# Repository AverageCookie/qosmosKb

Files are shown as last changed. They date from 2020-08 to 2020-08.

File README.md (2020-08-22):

# TKL keyboard "from scratch"

Being bored during the covid lockdown, I tried to learn a bit about electronics how my mechanical keyboard works. To practice, I wanted to build my own PCB, and why not try to build a usable keyboard.

## Disclamer : language mastery

I'm from France, I learn english mainly thanks to pop culture (TV shows/movies/videogames and lurking on reddit), so let me know if some sentences are gibberish or if I'm not clear enough.

## Table of Contents

* [Learning sources](#learning-sources)
* [Software/equipment/services used](#software-equipment-services-used)
* [Schematics](#schematics)
* [PCB](#pcb-design)
* [Soldering](#soldering)
* [Flashing Firmware](#flashing-firmware)
* [Troubles oh troubles](#troubles-oh-troubles)

## Learning sources

I learned how matrices works thanks to [r/MechanicalKeyboards/](https://www.reddit.com/r/MechanicalKeyboards/), and soon found [ruiqimao's awesome guide](https://github.com/ruiqimao/keyboard-pcb-guide). As you will see, the schematics I made are very similar to his.

## Software/equipment/services used

* For schematics and pcb design, I used [Kicad](https://kicad-pcb.org/).
* For pcb manufacturing, I went to [JLCPCB](https://jlcpcb.com/).
* For components, I went to [Digikey](https://www.digikey.com/) and [RS components](https://www.rs-online.com/)
* For soldering tools and materials, I bought from divers Amazon sellers :
    * [Soldering tools](https://www.amazon.fr/gp/product/B07PLTB46N/ref=ppx_yo_dt_b_asin_title_o06_s01?ie=UTF8&psc=1)
    * [Flux](https://www.amazon.fr/gp/product/B002OB4CIE/ref=ppx_yo_dt_b_asin_title_o05_s00)
    * [Solder](https://www.amazon.fr/gp/product/B07PDFF5NZ/ref=ppx_yo_dt_b_asin_title_o06_s01)
* For plate and case design, I used [Blender](https://www.blender.org/),
* For plate and case printing, I used my [Ender3](https://www.ender3.fr/) 3D printer.
* for switches and stabilizers, I bought from [kbdfans](https://kbdfans.com/)

## Schematics

Inspired by [u/Ryvaeus](https://www.reddit.com/r/MechanicalKeyboards/comments/4qdu9o/help_ive_planned_my_matrix_and_teensy_pinout_for/), I went for a 12*9 matrice :

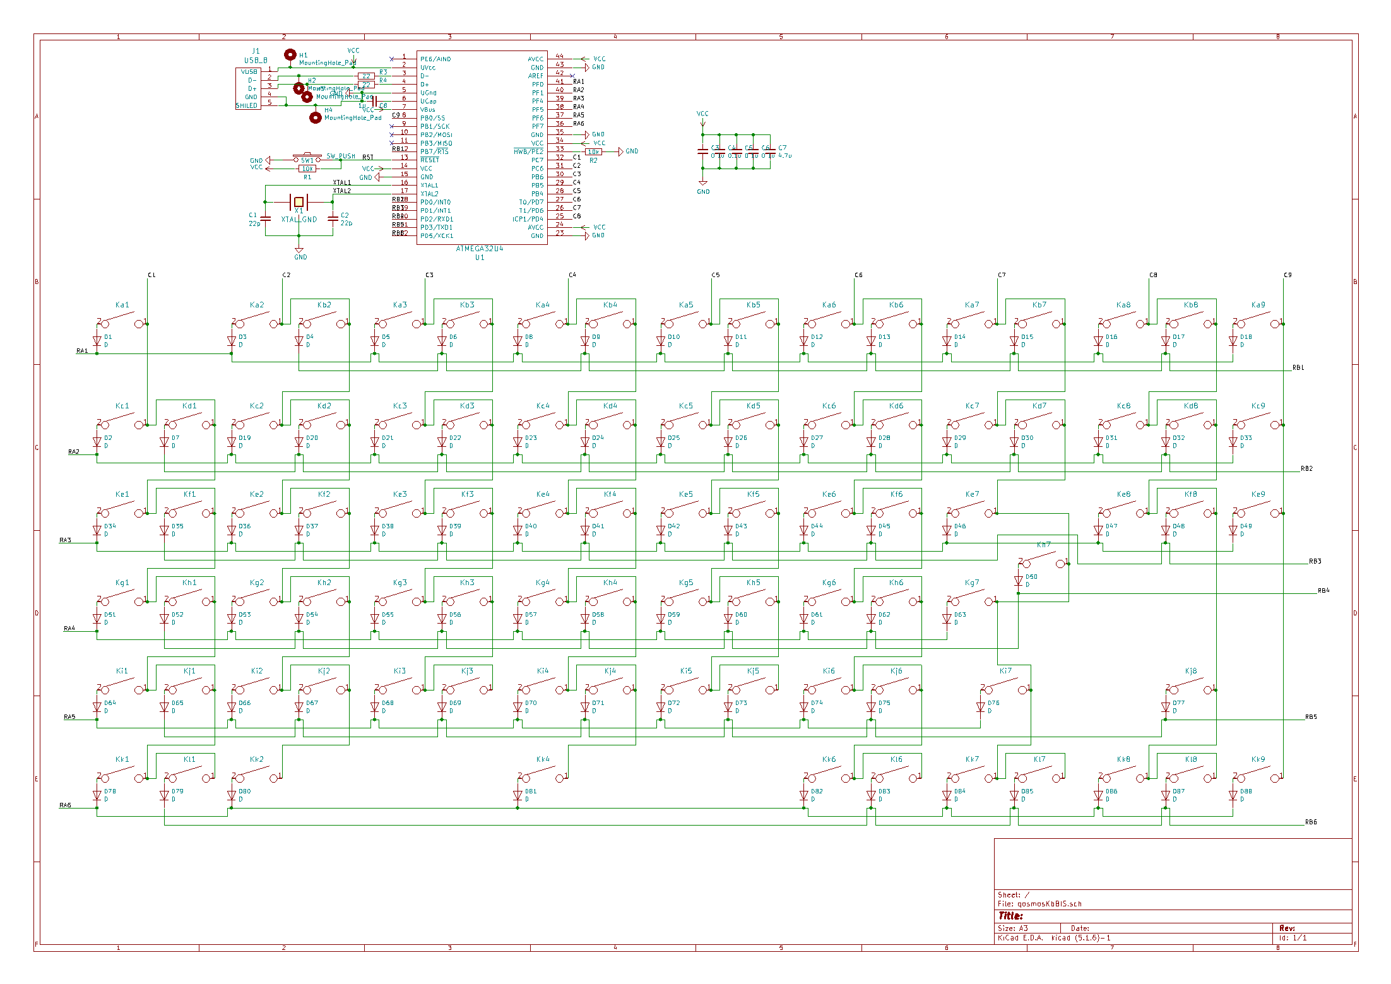
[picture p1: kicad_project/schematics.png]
Schematic


I did a first try with micro USB, but had a lot of problems soldering correctly, so I made a USB B + holes (so i can have an option to solder a non removable cable) 2nd version.

## PCB Design

It was the first PCB I designed, I'm pretty proud but I guess there might be a problem as you will see right bellow. 
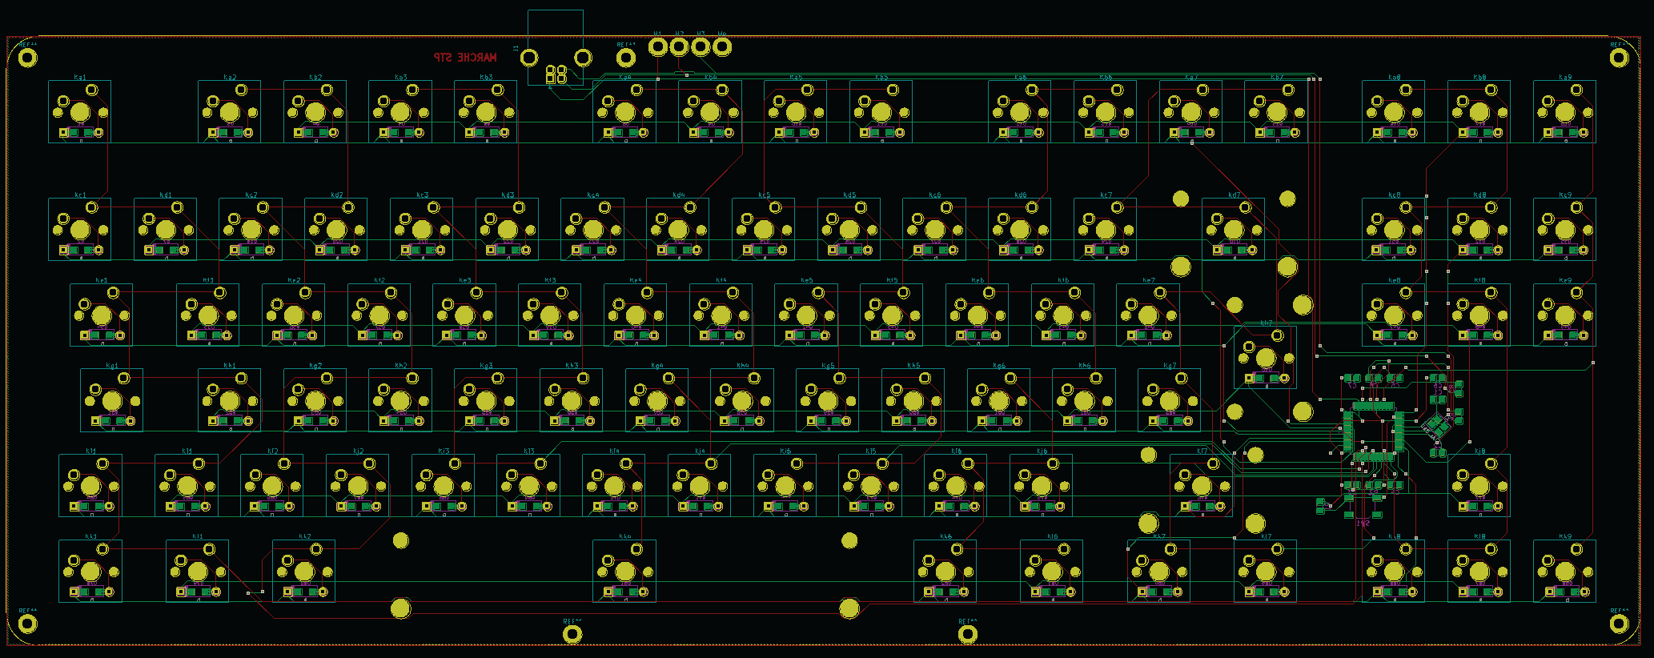
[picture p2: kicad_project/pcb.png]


## Soldering

I have not soldered diodes for now because of the issues you will learn about in the next chapter.

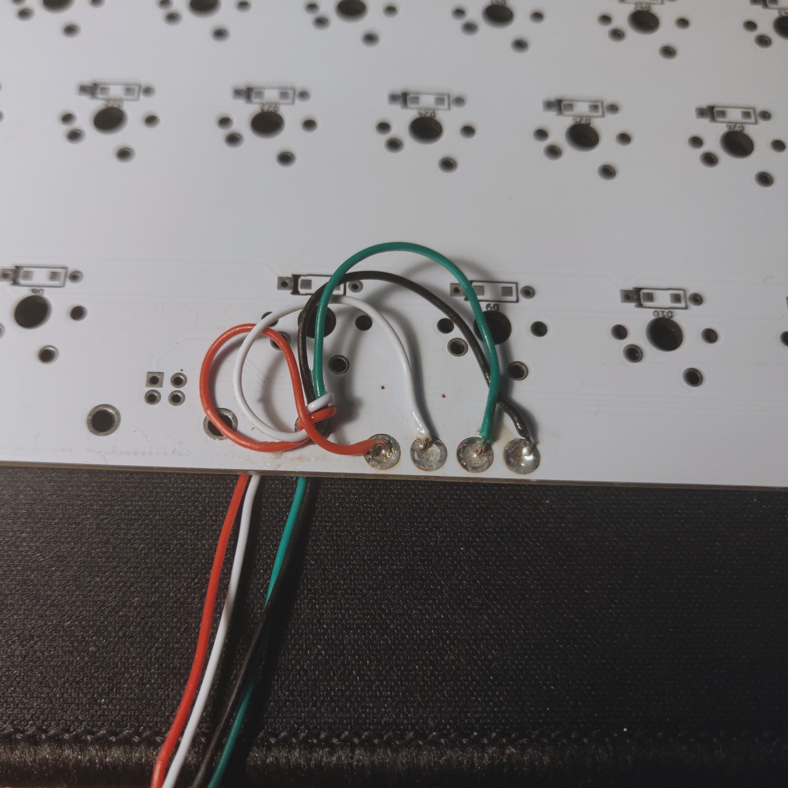
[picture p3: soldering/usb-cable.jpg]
USB cable soldering

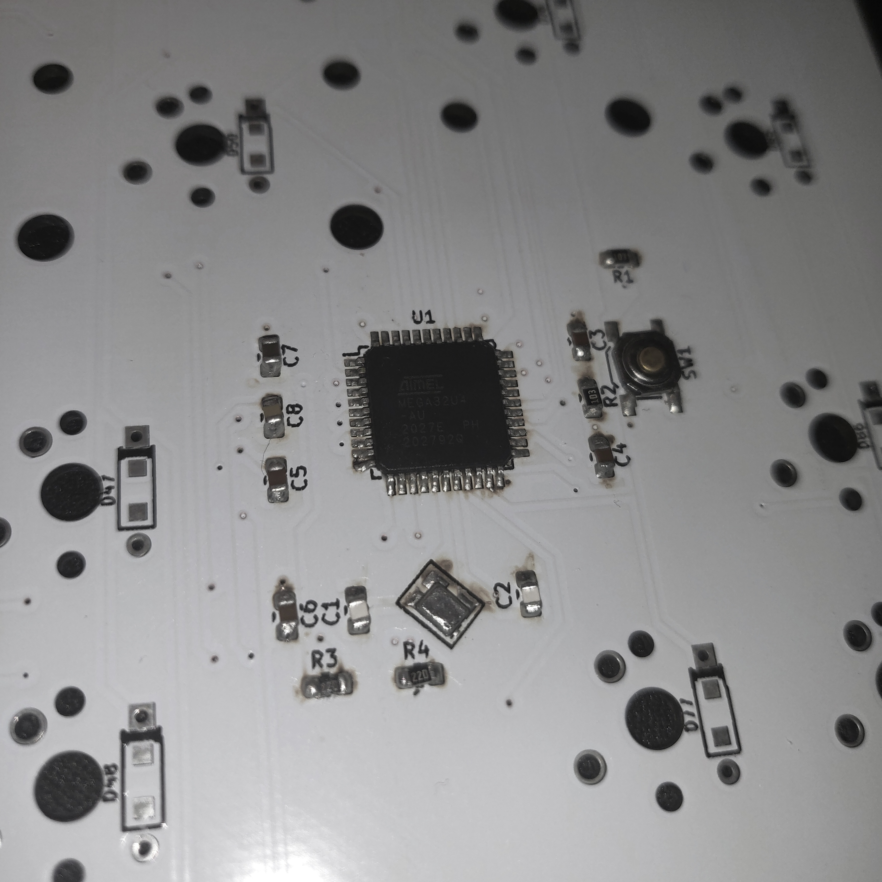
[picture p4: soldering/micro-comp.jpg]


## Flashing Firmware

I plugged it into my desktop, pressed the RESET button, and flashed it with QMK Toolbox (there was no error). But then nothing, so I unplugged and replugged it, to have windows tel me "USB descriptor failed".

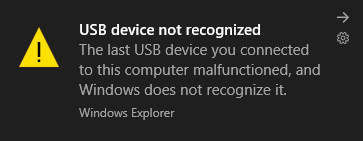
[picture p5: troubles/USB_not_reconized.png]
Screenshot Error 1

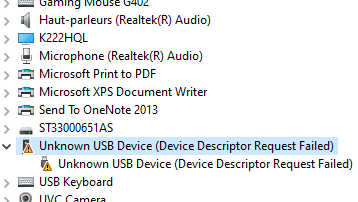
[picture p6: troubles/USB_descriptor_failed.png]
Screenshot Error 2


## Troubles oh troubles

I tried to re-install my USB controllers driver, I tried to flash a few more time, even changing from QMK toolbox to QMK flasher, but I could not make it work.

Then I tried to plug it on my laptop (XPS13, with USB C adaptator), and it was recognised as the keyboard it is destined to be !

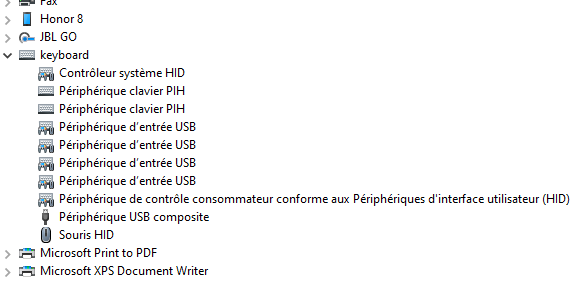
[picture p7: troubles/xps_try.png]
XPS success


Thinking the USB Male port could be the problem, I replaced the cable by one I know works perfectly. It was unproductive, and strangely it does not work anymore on my laptop (same errors as in my desktop) I tried again to re-install my USB controllers driver on both machines, nothing.

I tried to discharge capacitors before plugging it in, and it seems to connect and disconnect maybe 5 times before showing me the "USB descriptor failed" error.

I just tried to get into DFU mode by using the RESET button, and it does not even work..

You can find all the sources (except the v1 schematics, I cannot find it, I think I threw it) in the repo.

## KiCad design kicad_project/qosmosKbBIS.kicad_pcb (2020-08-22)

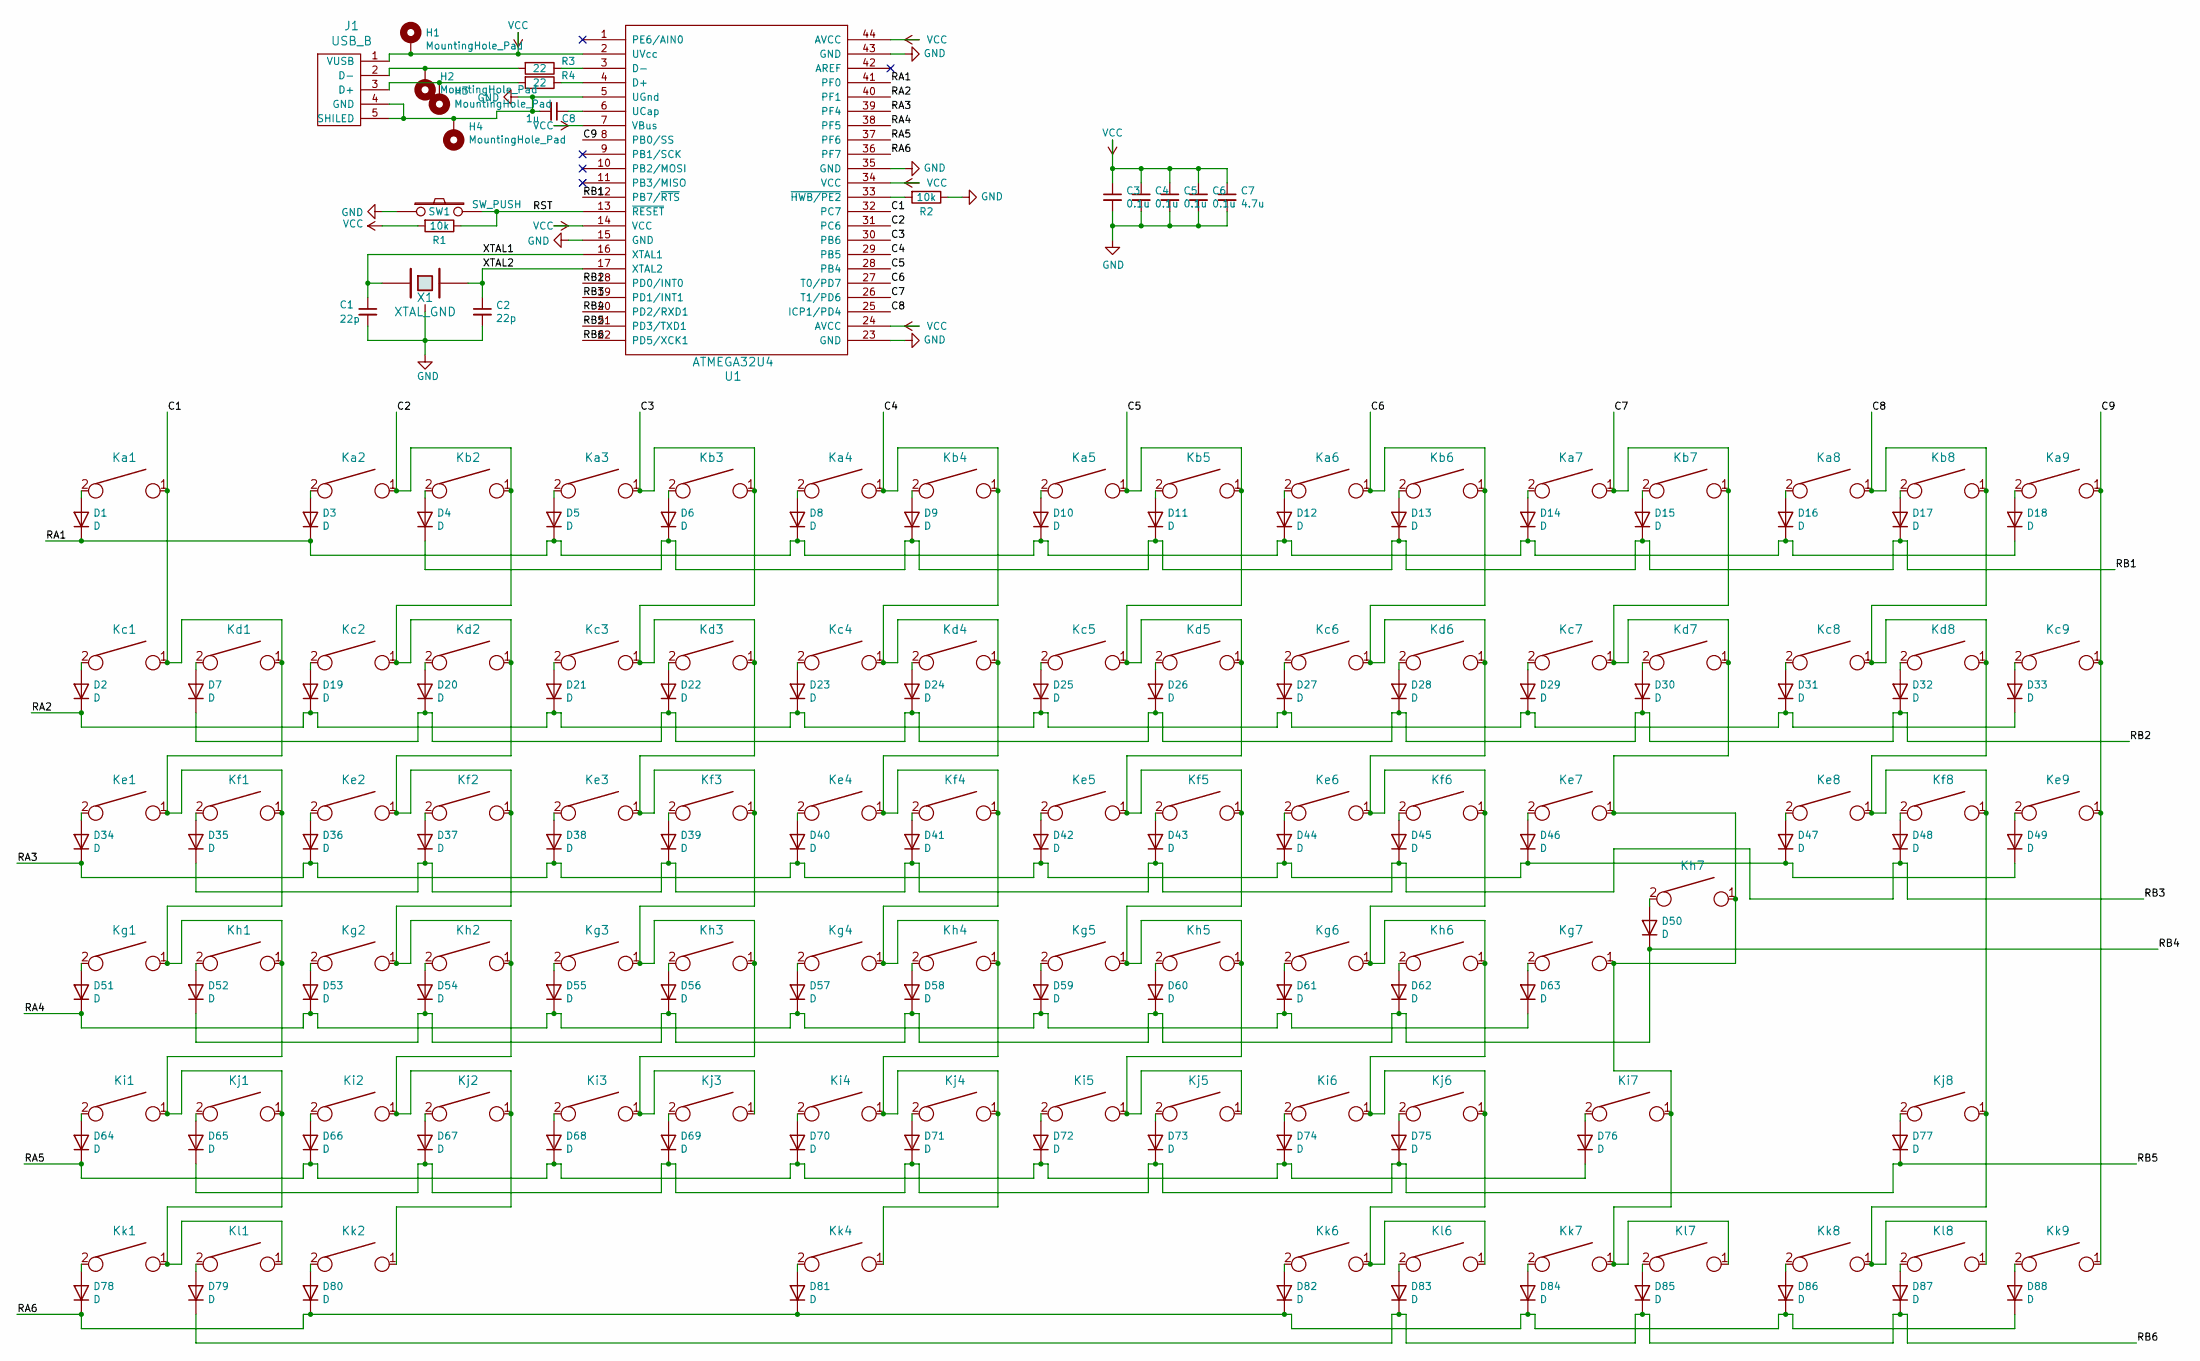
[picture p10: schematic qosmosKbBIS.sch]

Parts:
C1, C2: 22p; C_0805_2012Metric_Pad1.15x1.40mm_HandSolder
C3, C4, C5, C6: 0.1u; C_0805_2012Metric_Pad1.15x1.40mm_HandSolder
C7: 4.7u; C_0805_2012Metric_Pad1.15x1.40mm_HandSolder
C8: 1u; C_0805_2012Metric_Pad1.15x1.40mm_HandSolder
D1, D2, D3, D4, D5, D6, D7, D8, D9, D10, D11, D12, D13, D14, D15, D16, D17, D18, D19, D20, D21, D22, D23, D24, D25, D26, D27, D28, D29, D30, D31, D32, D33, D34, D35, D36, D37, D38, D39, D40, D41, D42, D43, D44, D45, D46, D47, D48, D49, D50, D51, D52, D53, D54, D55, D56, D57, D58, D59, D60, D61, D62, D63, D64, D65, D66, D67, D68, D69, D70, D71, D72, D73, D74, D75, D76, D77, D78, D79, D80, D81, D82, D83, D84, D85, D86, D87, D88: D; D_SOD123_axial
H1, H2, H3, H4: MountingHole_Pad; MountingHole_2.2mm_M2_ISO14580_Pad
J1: USB_B; USB_B_OST_USB-B1HSxx_Horizontal
Ka1, Ka2, Ka3, Ka4, Ka5, Ka6, Ka7, Ka8, Ka9: KEYSW; SW_Cherry_MX_1.00u_PCB
Kb2, Kb3, Kb4, Kb5, Kb6, Kb7, Kb8: KEYSW; SW_Cherry_MX_1.00u_PCB
Kc1, Kc2, Kc3, Kc4, Kc5, Kc6, Kc7, Kc8, Kc9: KEYSW; SW_Cherry_MX_1.00u_PCB
Kd1, Kd2, Kd3, Kd4, Kd5, Kd6, Kd8: KEYSW; SW_Cherry_MX_1.00u_PCB
Kd7: KEYSW; SW_Cherry_MX_2.00u_PCB
Ke1: KEYSW; SW_Cherry_MX_1.50u_PCB
Ke2, Ke3, Ke4, Ke5, Ke6, Ke7, Ke8, Ke9: KEYSW; SW_Cherry_MX_1.00u_PCB
Kf1, Kf2, Kf3, Kf4, Kf5, Kf6, Kf8: KEYSW; SW_Cherry_MX_1.00u_PCB
Kg1: KEYSW; SW_Cherry_MX_1.75u_PCB
Kg2, Kg3, Kg4, Kg5, Kg6, Kg7: KEYSW; SW_Cherry_MX_1.00u_PCB
Kh1, Kh2, Kh3, Kh4, Kh5, Kh6: KEYSW; SW_Cherry_MX_1.00u_PCB
Kh7: KEYSW; SW_Cherry_MX_ISOEnter_PCB
Ki1: KEYSW; SW_Cherry_MX_1.25u_PCB
Ki2, Ki3, Ki4, Ki5, Ki6: KEYSW; SW_Cherry_MX_1.00u_PCB
Ki7: KEYSW; SW_Cherry_MX_2.75u_PCB
Kj1, Kj2, Kj3, Kj4, Kj5, Kj6, Kj8: KEYSW; SW_Cherry_MX_1.00u_PCB
Kk1, Kk2, Kk6, Kk7: KEYSW; SW_Cherry_MX_1.25u_PCB
Kk4: KEYSW; SW_Cherry_MX_6.25u_PCB
Kk8, Kk9: KEYSW; SW_Cherry_MX_1.00u_PCB
Kl1, Kl6, Kl7: KEYSW; SW_Cherry_MX_1.25u_PCB
Kl8: KEYSW; SW_Cherry_MX_1.00u_PCB
R1, R2: 10k; R_0805_2012Metric_Pad1.15x1.40mm_HandSolder
R3, R4: 22; R_0805_2012Metric_Pad1.15x1.40mm_HandSolder
SW1: SW_PUSH; SW_SPST_TL3342
U1: ATMEGA32U4; TQFP-44_10x10mm_P0.8mm
X1: XTAL_GND; FA-238

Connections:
/C1: Ka1.1, Kc1.1, Kd1.1, Ke1.1, Kf1.1, Kg1.1, Kh1.1, Ki1.1, Kj1.1, Kk1.1, Kl1.1, U1.32 (PC7)
/C2: Ka2.1, Kb2.1, Kc2.1, Kd2.1, Ke2.1, Kf2.1, Kg2.1, Kh2.1, Ki2.1, Kj2.1, Kk2.1, U1.31 (PC6)
/C3: Ka3.1, Kb3.1, Kc3.1, Kd3.1, Ke3.1, Kf3.1, Kg3.1, Kh3.1, Ki3.1, Kj3.1, U1.30 (PB6)
/C4: Ka4.1, Kb4.1, Kc4.1, Kd4.1, Ke4.1, Kf4.1, Kg4.1, Kh4.1, Ki4.1, Kj4.1, Kk4.1, U1.29 (PB5)
/C5: Ka5.1, Kb5.1, Kc5.1, Kd5.1, Ke5.1, Kf5.1, Kg5.1, Kh5.1, Ki5.1, Kj5.1, U1.28 (PB4)
/C6: Ka6.1, Kb6.1, Kc6.1, Kd6.1, Ke6.1, Kf6.1, Kg6.1, Kh6.1, Ki6.1, Kj6.1, Kk6.1, Kl6.1, U1.27 (T0/PD7)
/C7: Ka7.1, Kb7.1, Kc7.1, Kd7.1, Ke7.1, Kg7.1, Kh7.1, Ki7.1, Kk7.1, Kl7.1, U1.26 (T1/PD6)
/C8: Ka8.1, Kb8.1, Kc8.1, Kd8.1, Ke8.1, Kf8.1, Kj8.1, Kk8.1, Kl8.1, U1.25 (ICP1/PD4)
/C9: Ka9.1, Kc9.1, Ke9.1, Kk9.1, U1.8 (PB0/SS)
/RA1: D1.1 (K), D3.1 (K), D5.1 (K), D8.1 (K), D10.1 (K), D12.1 (K), D14.1 (K), D16.1 (K), D18.1 (K), U1.41 (PF0)
/RA2: D2.1 (K), D19.1 (K), D21.1 (K), D23.1 (K), D25.1 (K), D27.1 (K), D29.1 (K), D31.1 (K), D33.1 (K), U1.40 (PF1)
/RA3: D34.1 (K), D36.1 (K), D38.1 (K), D40.1 (K), D42.1 (K), D44.1 (K), D46.1 (K), D47.1 (K), D49.1 (K), U1.39 (PF4)
/RA4: D51.1 (K), D53.1 (K), D55.1 (K), D57.1 (K), D59.1 (K), D61.1 (K), D63.1 (K), U1.38 (PF5)
/RA5: D64.1 (K), D66.1 (K), D68.1 (K), D70.1 (K), D72.1 (K), D74.1 (K), D76.1 (K), U1.37 (PF6)
/RA6: D78.1 (K), D80.1 (K), D81.1 (K), D82.1 (K), D84.1 (K), D86.1 (K), D88.1 (K), U1.36 (PF7)
/RB1: D4.1 (K), D6.1 (K), D9.1 (K), D11.1 (K), D13.1 (K), D15.1 (K), D17.1 (K), U1.12 (PB7/~RTS)
/RB2: D7.1 (K), D20.1 (K), D22.1 (K), D24.1 (K), D26.1 (K), D28.1 (K), D30.1 (K), D32.1 (K), U1.18 (PD0/INT0)
/RB3: D35.1 (K), D37.1 (K), D39.1 (K), D41.1 (K), D43.1 (K), D45.1 (K), D48.1 (K), U1.19 (PD1/INT1)
/RB4: D50.1 (K), D52.1 (K), D54.1 (K), D56.1 (K), D58.1 (K), D60.1 (K), D62.1 (K), U1.20 (PD2/RXD1)
/RB5: D65.1 (K), D67.1 (K), D69.1 (K), D71.1 (K), D73.1 (K), D75.1 (K), D77.1 (K), U1.21 (PD3/TXD1)
/RB6: D79.1 (K), D83.1 (K), D85.1 (K), D87.1 (K), U1.22 (PD5/XCK1)
/RST: R1.1, SW1.2, U1.13 (~RESET)
/XTAL1: C1.1, U1.16 (XTAL1), X1.1
/XTAL2: C2.1, U1.17 (XTAL2), X1.2
GND: C1.2, C2.2, C3.2, C4.2, C5.2, C6.2, C7.2, C8.2, H4.1, J1.4 (GND), J1.5 (SHILED), R2.1, SW1.1, U1.5 (UGnd), U1.15 (GND), U1.23 (GND), U1.35 (GND), U1.43 (GND), X1.3
unnamed: C8.1, U1.6 (UCap)
unnamed: D1.2 (A), Ka1.2
unnamed: D2.2 (A), Kc1.2
unnamed: D3.2 (A), Ka2.2
unnamed: D4.2 (A), Kb2.2
unnamed: D5.2 (A), Ka3.2
unnamed: D6.2 (A), Kb3.2
unnamed: D7.2 (A), Kd1.2
unnamed: D8.2 (A), Ka4.2
unnamed: D9.2 (A), Kb4.2
unnamed: D10.2 (A), Ka5.2
unnamed: D11.2 (A), Kb5.2
unnamed: D12.2 (A), Ka6.2
unnamed: D13.2 (A), Kb6.2
unnamed: D14.2 (A), Ka7.2
unnamed: D15.2 (A), Kb7.2
unnamed: D16.2 (A), Ka8.2
unnamed: D17.2 (A), Kb8.2
unnamed: D18.2 (A), Ka9.2
unnamed: D19.2 (A), Kc2.2
unnamed: D20.2 (A), Kd2.2
unnamed: D21.2 (A), Kc3.2
unnamed: D22.2 (A), Kd3.2
unnamed: D23.2 (A), Kc4.2
unnamed: D24.2 (A), Kd4.2
unnamed: D25.2 (A), Kc5.2
unnamed: D26.2 (A), Kd5.2
unnamed: D27.2 (A), Kc6.2
unnamed: D28.2 (A), Kd6.2
unnamed: D29.2 (A), Kc7.2
unnamed: D30.2 (A), Kd7.2
unnamed: D31.2 (A), Kc8.2
unnamed: D32.2 (A), Kd8.2
unnamed: D33.2 (A), Kc9.2
unnamed: D34.2 (A), Ke1.2
unnamed: D35.2 (A), Kf1.2
unnamed: D36.2 (A), Ke2.2
unnamed: D37.2 (A), Kf2.2
unnamed: D38.2 (A), Ke3.2
unnamed: D39.2 (A), Kf3.2
unnamed: D40.2 (A), Ke4.2
unnamed: D41.2 (A), Kf4.2
unnamed: D42.2 (A), Ke5.2
unnamed: D43.2 (A), Kf5.2
unnamed: D44.2 (A), Ke6.2
unnamed: D45.2 (A), Kf6.2
unnamed: D46.2 (A), Ke7.2
unnamed: D47.2 (A), Ke8.2
unnamed: D48.2 (A), Kf8.2
unnamed: D49.2 (A), Ke9.2
unnamed: D50.2 (A), Kh7.2
unnamed: D51.2 (A), Kg1.2
unnamed: D52.2 (A), Kh1.2
unnamed: D53.2 (A), Kg2.2
unnamed: D54.2 (A), Kh2.2
unnamed: D55.2 (A), Kg3.2
unnamed: D56.2 (A), Kh3.2
unnamed: D57.2 (A), Kg4.2
unnamed: D58.2 (A), Kh4.2
unnamed: D59.2 (A), Kg5.2
unnamed: D60.2 (A), Kh5.2
unnamed: D61.2 (A), Kg6.2
unnamed: D62.2 (A), Kh6.2
unnamed: D63.2 (A), Kg7.2
unnamed: D64.2 (A), Ki1.2
unnamed: D65.2 (A), Kj1.2
unnamed: D66.2 (A), Ki2.2
unnamed: D67.2 (A), Kj2.2
unnamed: D68.2 (A), Ki3.2
unnamed: D69.2 (A), Kj3.2
unnamed: D70.2 (A), Ki4.2
unnamed: D71.2 (A), Kj4.2
unnamed: D72.2 (A), Ki5.2
unnamed: D73.2 (A), Kj5.2
unnamed: D74.2 (A), Ki6.2
unnamed: D75.2 (A), Kj6.2
unnamed: D76.2 (A), Ki7.2
unnamed: D77.2 (A), Kj8.2
unnamed: D78.2 (A), Kk1.2
unnamed: D79.2 (A), Kl1.2
unnamed: D80.2 (A), Kk2.2
unnamed: D81.2 (A), Kk4.2
unnamed: D82.2 (A), Kk6.2
unnamed: D83.2 (A), Kl6.2
unnamed: D84.2 (A), Kk7.2
unnamed: D85.2 (A), Kl7.2
unnamed: D86.2 (A), Kk8.2
unnamed: D87.2 (A), Kl8.2
unnamed: D88.2 (A), Kk9.2
unnamed: H2.1, J1.2 (D-), R3.2
unnamed: H3.1, J1.3 (D+), R4.2
unnamed: R2.2, U1.33 (~HWB/PE2)
unnamed: R3.1, U1.3 (D-)
unnamed: R4.1, U1.4 (D+)
VCC: C3.1, C4.1, C5.1, C6.1, C7.1, H1.1, J1.1 (VUSB), R1.2, U1.2 (UVcc), U1.7 (VBus), U1.14 (VCC), U1.24 (AVCC), U1.34 (VCC), U1.44 (AVCC)

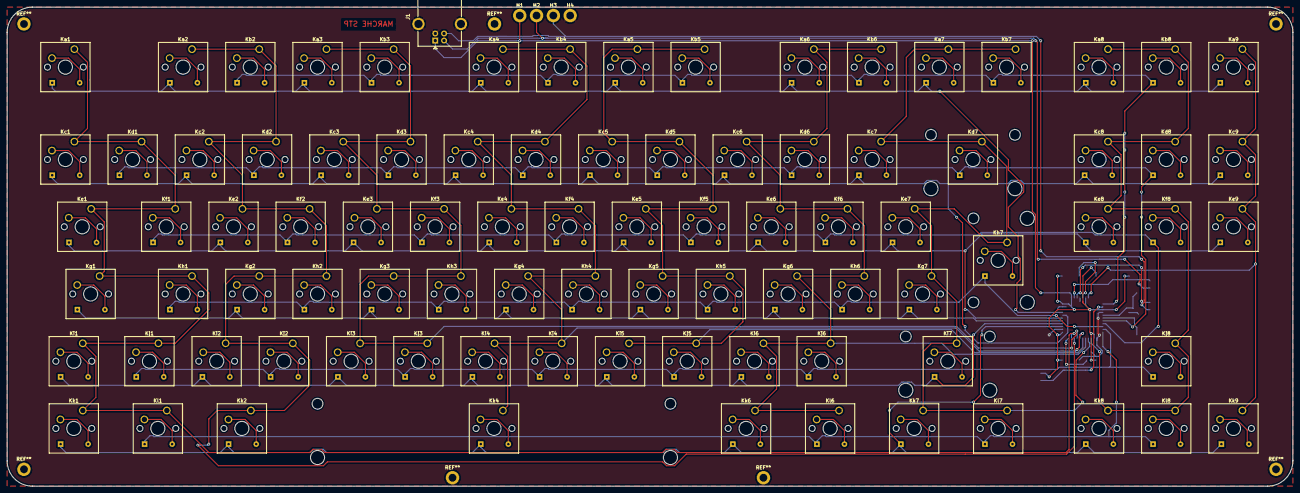
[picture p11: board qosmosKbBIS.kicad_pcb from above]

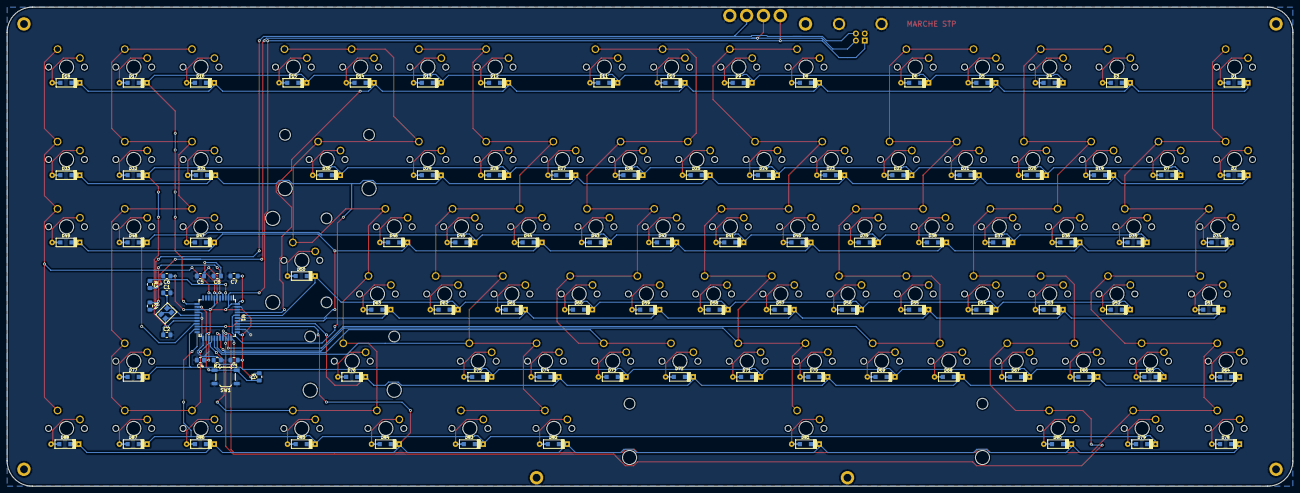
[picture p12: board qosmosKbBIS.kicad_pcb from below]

Board: 2 copper layers, 364.3 x 135.7 mm, 196 parts (103 on the bottom side), 120 nets.

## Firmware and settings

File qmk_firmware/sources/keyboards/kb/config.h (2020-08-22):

#ifndef CONFIG_H
#define CONFIG_H

#include "config_common.h"

/* USB Device descriptor parameter */
#define VENDOR_ID       0xFEED
#define PRODUCT_ID      0x6060
#define DEVICE_VER      0x0001
#define MANUFACTURER    qmkbuilder
#define PRODUCT         keyboard
#define DESCRIPTION     Keyboard

/* key matrix size */
#define MATRIX_ROWS 12
#define MATRIX_COLS 9

/* key matrix pins */
#define MATRIX_ROW_PINS { F0, B7, F1, D0, F4, D1, F5, D2, F6, D3, F7, D5 }
#define MATRIX_COL_PINS { C7, C6, B6, B5, B4, D7, D6, D4, B0 }
#define UNUSED_PINS

/* COL2ROW or ROW2COL */
#define DIODE_DIRECTION COL2ROW

/* number of backlight levels */

#ifdef BACKLIGHT_PIN
#define BACKLIGHT_LEVELS 0
#endif

/* Set 0 if debouncing isn't needed */
#define DEBOUNCING_DELAY 5

/* Mechanical locking support. Use KC_LCAP, KC_LNUM or KC_LSCR instead in keymap */
#define LOCKING_SUPPORT_ENABLE

/* Locking resynchronize hack */
#define LOCKING_RESYNC_ENABLE

/* key combination for command */
#define IS_COMMAND() ( \
    keyboard_report->mods == (MOD_BIT(KC_LSHIFT) | MOD_BIT(KC_RSHIFT)) \
)

/* prevent stuck modifiers */
#define PREVENT_STUCK_MODIFIERS


#ifdef RGB_DI_PIN
#define RGBLIGHT_ANIMATIONS
#define RGBLED_NUM 0
#define RGBLIGHT_HUE_STEP 8
#define RGBLIGHT_SAT_STEP 8
#define RGBLIGHT_VAL_STEP 8
#endif

#endif
